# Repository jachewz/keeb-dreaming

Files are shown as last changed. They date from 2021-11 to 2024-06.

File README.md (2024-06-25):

# keeb-dreaming
Build a 68% keyboard pcb and case

Assembled keyboard (bought the caps and switches):

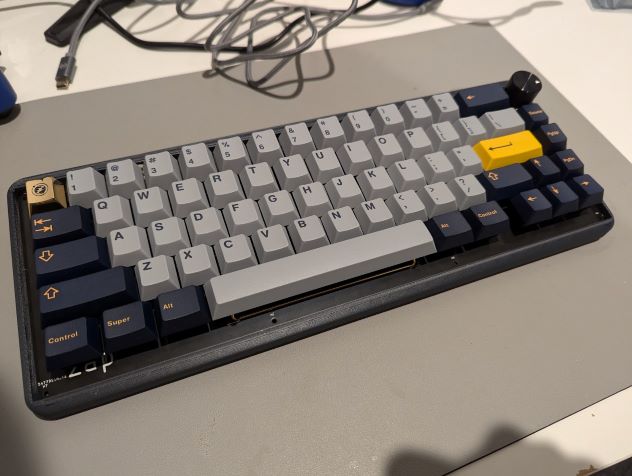
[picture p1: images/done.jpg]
Assembled keyboard with keycaps


## Features
- USB-C
- Volume knob + mute button
- Compression fit of pcb with case, no fasteners needed

## PCB

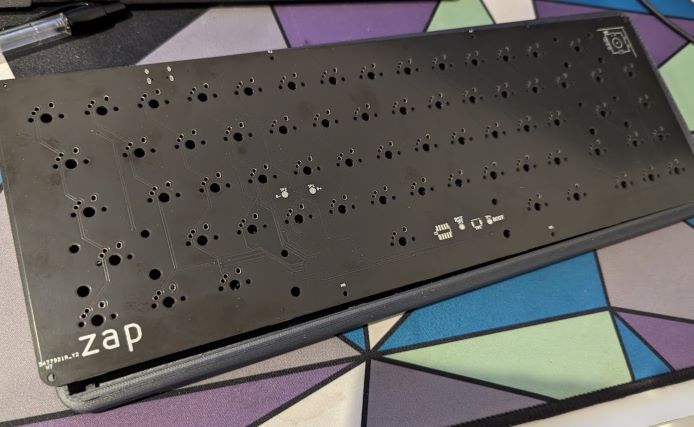
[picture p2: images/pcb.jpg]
PCB


- Learned from https://wiki.ai03.com/books/pcb-design/chapter/pcb-designer-guide
- Use KiCAD to edit the schematics and pcb design

## Firmware
- Copy [this folder](qmk/zap) into the [QMK repository's keyboards folder](https://github.com/qmk/qmk_firmware/tree/master/keyboards)
- Use the [QMK MSYS terminal tool](https://docs.qmk.fm/#/newbs_getting_started) and run `qmk compile -kb zap -km default`
- Alternatively, if you have a c compiler and make installed, run `make zap`
#### Flashing
- `make zap:default:flash`
- If that does not work try power cycling/resetting while shorting the BOOT0 pin to ground (exposed on the PCB, feel free to solder a switch on it).
- Use the [STM32 programmer](https://www.st.com/en/development-tools/stm32cubeprog.html) for further debugging and validating.

## Case

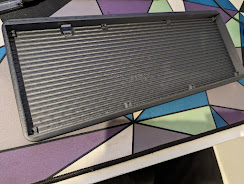
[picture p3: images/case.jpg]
Case


- In the picture above is this [case](case/3d), 3D printed, modeled using SolidWorks (free-trial)
- A layered version is also in the [case/layered](case/layered) folder

### Note
- The tolerance of the case is very small with the PCB, super tight fitting. Probably because 3D prints expand. Adjust the sizing of either the case or the PCB, and use M2 screws to fasten if needed.
- The USB-C hole needs to be higher/taller, make sure to edit it to leave at most 10mm material from the edge. The one in the picture had its hole expanded post production.
- Adding to the point above, foam can be added below but may change the placing of the USB-C hole.

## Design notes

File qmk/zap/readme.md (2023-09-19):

# zap

zap

*A short description of the keyboard/project*

* Keyboard Maintainer: [Jackson Hew](https://github.com/jacksonhew)
* Hardware Supported: *The PCBs, controllers supported*
* Hardware Availability: *Links to where you can find this hardware*

Make example for this keyboard (after setting up your build environment):

    make zap:default

Flashing example for this keyboard:

    make zap:default:flash

See the [build environment setup](https://docs.qmk.fm/#/getting_started_build_tools) and the [make instructions](https://docs.qmk.fm/#/getting_started_make_guide) for more information. Brand new to QMK? Start with our [Complete Newbs Guide](https://docs.qmk.fm/#/newbs).

## Bootloader

Enter the bootloader in 3 ways:

* **Bootmagic reset**: Hold down the key at (0,0) in the matrix (usually the top left key or Escape) and plug in the keyboard
* **Physical reset button**: Briefly press the button on the back of the PCB - some may have pads you must short instead
* **Keycode in layout**: Press the key mapped to `QK_BOOT` if it is available

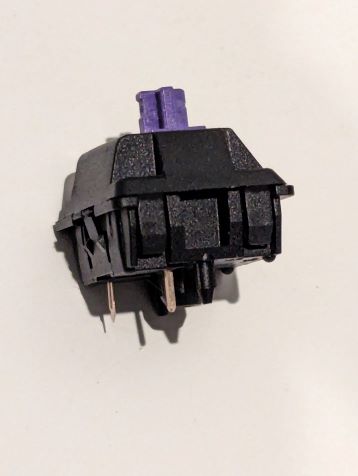
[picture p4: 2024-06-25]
images/purple_switch_shit_stems.jpg

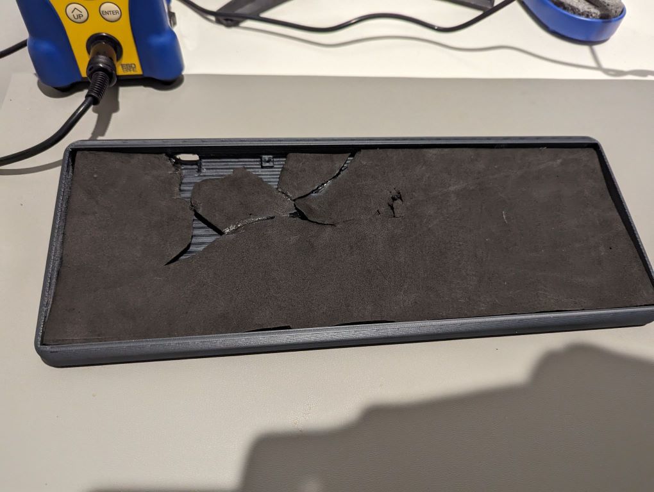
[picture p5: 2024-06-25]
images/foam.jpg

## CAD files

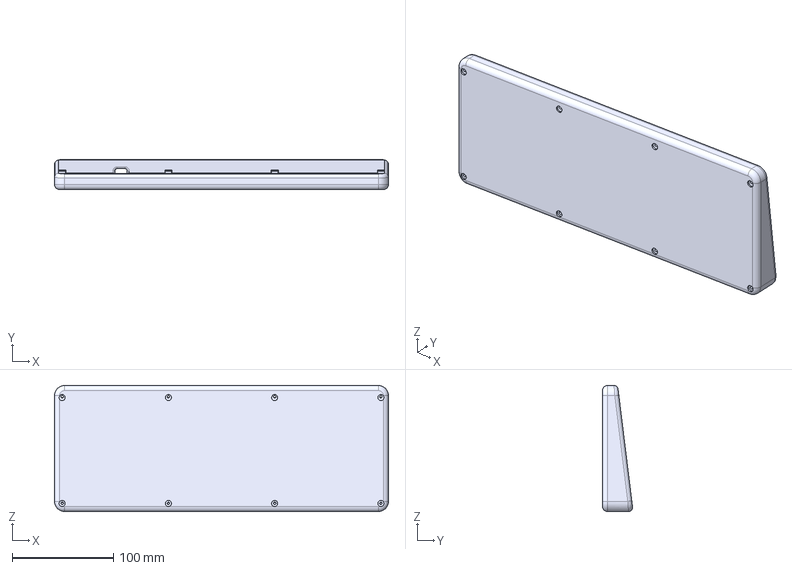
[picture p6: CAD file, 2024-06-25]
case/3d/case.step
329.4 x 29.7 x 124.3 mm

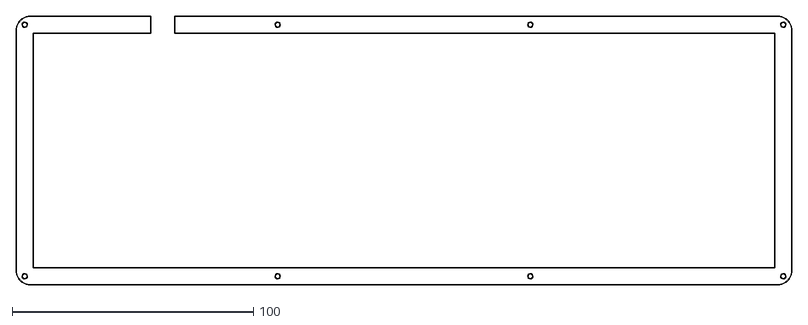
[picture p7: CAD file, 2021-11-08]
case/layered/open.dxf
321.3 x 111.3

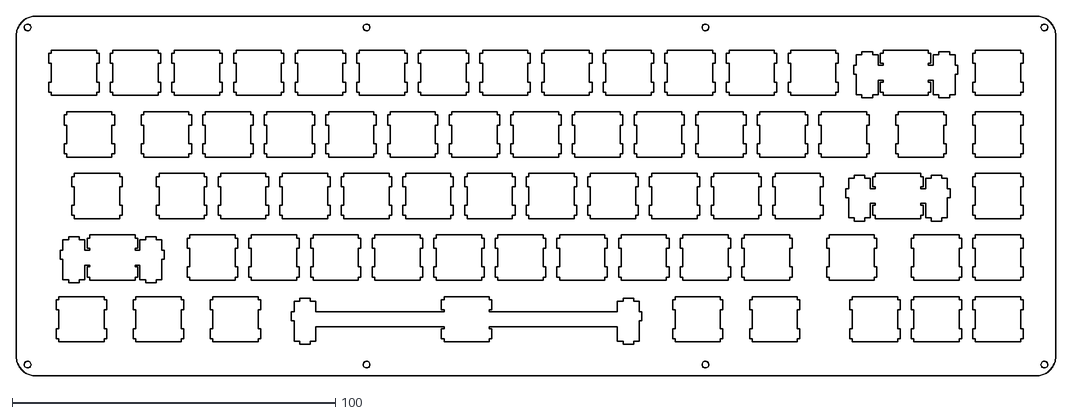
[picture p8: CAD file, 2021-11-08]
case/layered/key.dxf
321.3 x 111.3

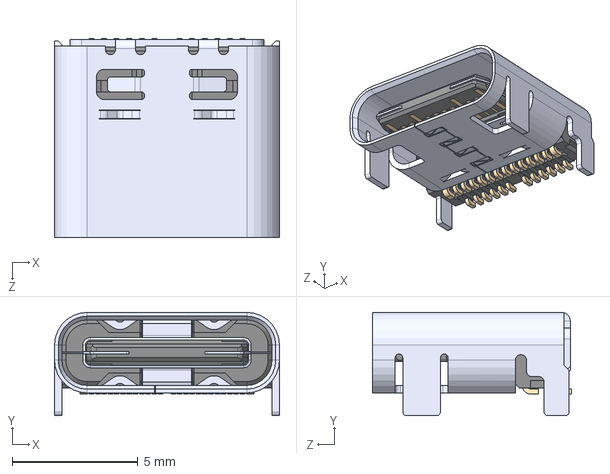
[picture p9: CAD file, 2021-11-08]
pcb/Molex Type C/105450-0101.step
8.94 x 4.10 x 7.90 mm

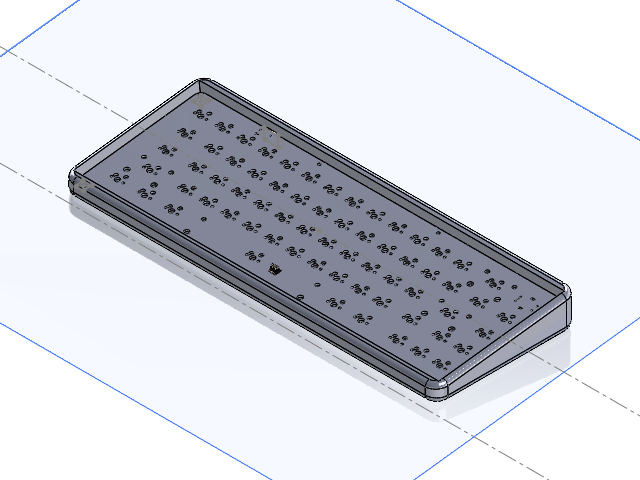
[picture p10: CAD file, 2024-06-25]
case/3d/keyboard.SLDASM
case
PinHeader_2x05_P127mm_Vertical_SMD_1.step
C_0805_2012Metric-0_1.step x 8
D_SOD_123_1.step x 67
Fuse_1206_3216Metric-1_1.step
R_0805_2012Metric-2_1.step x 5
SOT_23_6_1.step
SOT_23_1.step x 2
LQFP_48_7x7mm_P05mm_1.step
_autosave-myfirst_keeb_pcb PCB_1.step

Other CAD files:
case/3d/case.SLDPRT
case/3d/case.stl

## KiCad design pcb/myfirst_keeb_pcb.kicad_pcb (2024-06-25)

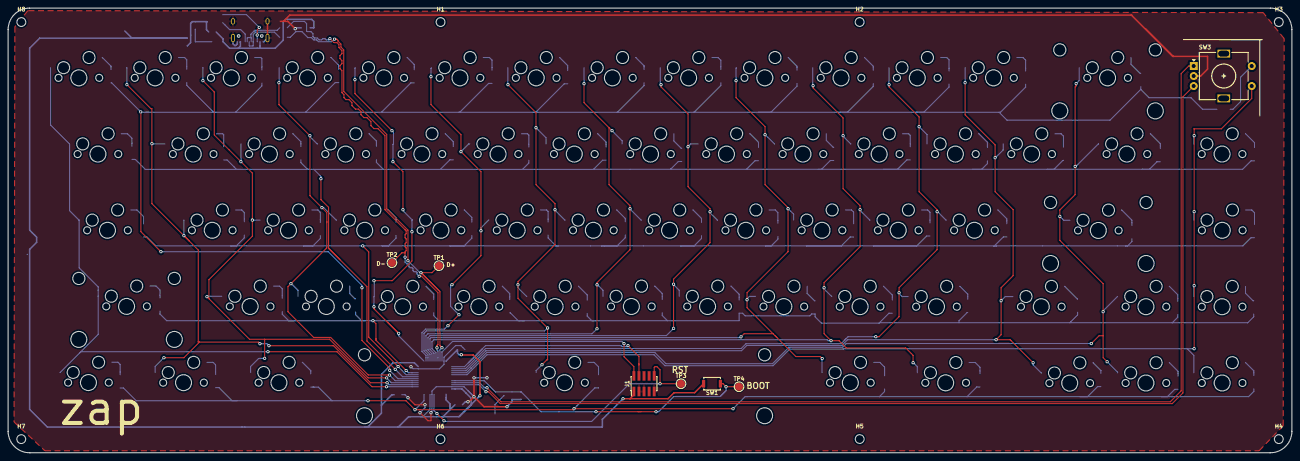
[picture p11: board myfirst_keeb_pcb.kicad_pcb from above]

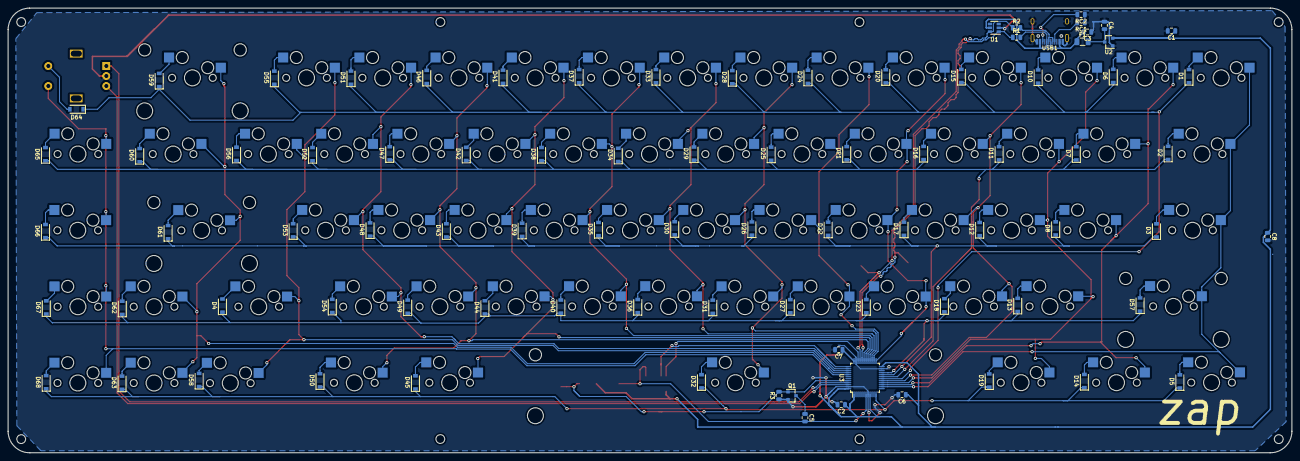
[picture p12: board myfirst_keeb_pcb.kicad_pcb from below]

Board: 2 copper layers, 320.9 x 111.1 mm, 167 parts (86 on the bottom side), 104 nets.

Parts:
C1, C2, C3, C4, C6, C7: 100nF; C_0805_2012Metric
C5: 100uF; C_0805_2012Metric
C8: 4.7uF; C_0805_2012Metric
D1, D2, D3, D4, D5, D6, D7, D8, D10, D11, D12, D13, D14, D15, D16, D17, D18, D19, D20, D21, D22, D23, D24, D25, D26, D27, D28, D29, D30, D31, D32, D33, D34, D35, D36, D37, D38, D39, D40, D41, D42, D43, D44, D45, D46, D47, D48, D49, D50, D51, D52, D53, D54, D55, D56, D57, D58, D59, D60, D61, D62, D63, D64, D65, D66, D67, D68: SOD_123; D_SOD-123
F1: 500mA; Fuse_1206_3216Metric
H1, H2, H3, H4, H5, H6, H7, H8: MountingHole; MountingHole_2.2mm_M2
J1: Conn_ARM_JTAG_SWD_10; PinHeader_2x05_P1.27mm_Vertical_SMD
MX1: ESC; MXOnly-1U-Hotswap
MX2: Tab; MXOnly-1.5U-Hotswap
MX3: CapsLk; MXOnly-1.75U-Hotswap
MX4: RShift; MXOnly-1.75U-Hotswap
MX5: Ctrl; MXOnly-1.25U-Hotswap
MX6: 1; MXOnly-1U-Hotswap
MX7: Q; MXOnly-1U-Hotswap
MX8: A; MXOnly-1U-Hotswap
MX10: 2; MXOnly-1U-Hotswap
MX11: W; MXOnly-1U-Hotswap
MX12: S; MXOnly-1U-Hotswap
MX13: Z; MXOnly-1U-Hotswap
MX14: Super; MXOnly-1.25U-Hotswap
MX15: 3; MXOnly-1U-Hotswap
MX16: E; MXOnly-1U-Hotswap
MX17: D; MXOnly-1U-Hotswap
MX18: X; MXOnly-1U-Hotswap
MX19: LAlt; MXOnly-1.25U-Hotswap
MX20: 4; MXOnly-1U-Hotswap
MX21: R; MXOnly-1U-Hotswap
MX22: F; MXOnly-1U-Hotswap
MX23: C; MXOnly-1U-Hotswap
MX24: 5; MXOnly-1U-Hotswap
MX25: T; MXOnly-1U-Hotswap
MX26: G; MXOnly-1U-Hotswap
MX27: V; MXOnly-1U-Hotswap
MX28: 6; MXOnly-1U-Hotswap
MX29: Y; MXOnly-1U-Hotswap
MX30: H; MXOnly-1U-Hotswap
MX31: B; MXOnly-1U-Hotswap
MX32: Space; MXOnly-6.25U-Hotswap
MX33: 7; MXOnly-1U-Hotswap
MX34: U; MXOnly-1U-Hotswap
MX35: J; MXOnly-1U-Hotswap
MX36: N; MXOnly-1U-Hotswap
MX37: 8; MXOnly-1U-Hotswap
MX38: I; MXOnly-1U-Hotswap
MX39: K; MXOnly-1U-Hotswap
MX40: M; MXOnly-1U-Hotswap
MX41: 9; MXOnly-1U-Hotswap
MX42: O; MXOnly-1U-Hotswap
MX43: L; MXOnly-1U-Hotswap
MX44: ,; MXOnly-1U-Hotswap
MX45: RAlt; MXOnly-1.25U-Hotswap
MX46: 0; MXOnly-1U-Hotswap
MX47: P; MXOnly-1U-Hotswap
MX48: ;; MXOnly-1U-Hotswap
MX49: .; MXOnly-1U-Hotswap
MX50: Fn; MXOnly-1.25U-Hotswap
MX51: _; MXOnly-1U-Hotswap
MX52: {; MXOnly-1U-Hotswap
MX53: "; MXOnly-1U-Hotswap
MX54: /; MXOnly-1U-Hotswap
MX55: +; MXOnly-1U-Hotswap
MX56: }; MXOnly-1U-Hotswap
MX57: LShift; MXOnly-2.25U-Hotswap
MX58: Left; MXOnly-1U-Hotswap
MX59: Backspace; MXOnly-2U-Hotswap
MX60: |; MXOnly-1.5U-Hotswap
MX61: Enter; MXOnly-2.25U-Hotswap
MX62: Up; MXOnly-1U-Hotswap
MX63: Down; MXOnly-1U-Hotswap
MX64: Del; MXOnly-1U-Hotswap
MX65: PageUp; MXOnly-1U-Hotswap
MX66: PageDown; MXOnly-1U-Hotswap
MX67: Right; MXOnly-1U-Hotswap
Q1: DTC123J; SOT-23
R1, R2: 22; R_0805_2012Metric
R3: 10k; R_0805_2012Metric
RC1, RC2: 5k1; R_0805_2012Metric
SW1: SW_Push; SW_Push_SPST_NO_Alps_SKRK
SW3: Rotary_Encoder_Switch; RotaryEncoder_Alps_EC11E-Switch_Vertical_H20mm
TP1, TP2, TP3, TP4: TestPoint; TestPoint_Pad_D2.0mm
U1: SRV05-4; SOT-23-6
U2: MCP1700-3302E_SOT23; SOT-23
U3: STM32F072CBTx; LQFP-48_7x7mm_P0.5mm
USB1: HRO-TYPE-C-31-M-12; HRO-TYPE-C-31-M-12-Assembly

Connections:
+3V3: C1.1, C2.1, C6.1, C7.1, C8.1, J1.1, SW1.2, U2.2, U3.1, U3.9, U3.24, U3.36, U3.48
BOOT0: Q1.1, R3.2, SW1.1, TP4.1, U3.44
COL0: MX1.1, MX2.1, MX3.1, MX5.1, MX57.1, U3.14
COL1: MX6.1, MX7.1, MX8.1, MX14.1, U3.15
COL2: MX10.1, MX11.1, MX12.1, MX13.1, MX19.1, U3.16
COL3: MX15.1, MX16.1, MX17.1, MX18.1, U3.17
COL4: MX20.1, MX21.1, MX22.1, MX23.1, U3.25
COL5: MX24.1, MX25.1, MX26.1, MX27.1, U3.26
COL6: MX28.1, MX29.1, MX30.1, MX31.1, MX32.1, U3.27
COL7: MX33.1, MX34.1, MX35.1, MX36.1, U3.28
COL8: MX37.1, MX38.1, MX39.1, MX40.1, U3.29
COL9: MX41.1, MX42.1, MX43.1, MX44.1, MX45.1, U3.30
COL10: MX46.1, MX47.1, MX48.1, MX49.1, MX50.1, U3.31
COL11: MX51.1, MX52.1, MX53.1, MX54.1, U3.38
COL12: MX4.1, MX55.1, MX56.1, MX58.1, U3.39
COL13: MX59.1, MX60.1, MX61.1, MX62.1, MX63.1, U3.40
COL14: MX64.1, MX65.1, MX66.1, MX67.1, SW3.S1, U3.41
D+: R1.1, TP1.1, U1.1, U3.33
D-: R2.1, TP2.1, U1.6, U3.32
ENCODER_A: SW3.A, U3.45
ENCODER_B: SW3.B, U3.46
GND: C1.2, C2.2, C3.1, C4.1, C6.2, C7.2, C8.2, J1.3, J1.5, J1.9, Q1.2, R3.1, RC1.1, RC2.1, SW3.C, U1.2, U2.1, U3.8, U3.23, U3.35, U3.47, USB1.1, USB1.12, USB1.13
NRST: C5.2, J1.10, TP3.1, U3.7
unnamed: C4.2, F1.2, U2.3
unnamed: C5.1, Q1.3
unnamed: D1.2, MX1.2
unnamed: D2.2, MX2.2
unnamed: D3.2, MX3.2
unnamed: D4.2, MX4.2
unnamed: D5.2, MX5.2
unnamed: D6.2, MX6.2
unnamed: D7.2, MX7.2
unnamed: D8.2, MX8.2
unnamed: D10.2, MX10.2
unnamed: D11.2, MX11.2
unnamed: D12.2, MX12.2
unnamed: D13.2, MX13.2
unnamed: D14.2, MX14.2
unnamed: D15.2, MX15.2
unnamed: D16.2, MX16.2
unnamed: D17.2, MX17.2
unnamed: D18.2, MX18.2
unnamed: D19.2, MX19.2
unnamed: D20.2, MX20.2
unnamed: D21.2, MX21.2
unnamed: D22.2, MX22.2
unnamed: D23.2, MX23.2
unnamed: D24.2, MX24.2
unnamed: D25.2, MX25.2
unnamed: D26.2, MX26.2
unnamed: D27.2, MX27.2
unnamed: D28.2, MX28.2
unnamed: D29.2, MX29.2
unnamed: D30.2, MX30.2
unnamed: D31.2, MX31.2
unnamed: D32.2, MX32.2
unnamed: D33.2, MX33.2
unnamed: D34.2, MX34.2
unnamed: D35.2, MX35.2
unnamed: D36.2, MX36.2
unnamed: D37.2, MX37.2
unnamed: D38.2, MX38.2
unnamed: D39.2, MX39.2
unnamed: D40.2, MX40.2
unnamed: D41.2, MX41.2
unnamed: D42.2, MX42.2
unnamed: D43.2, MX43.2
unnamed: D44.2, MX44.2
unnamed: D45.2, MX45.2
unnamed: D46.2, MX46.2
unnamed: D47.2, MX47.2
unnamed: D48.2, MX48.2
unnamed: D49.2, MX49.2
unnamed: D50.2, MX50.2
unnamed: D51.2, MX51.2
unnamed: D52.2, MX52.2
unnamed: D53.2, MX53.2
unnamed: D54.2, MX54.2
unnamed: D55.2, MX55.2
unnamed: D56.2, MX56.2
unnamed: D57.2, MX57.2
unnamed: D58.2, MX58.2
unnamed: D59.2, MX59.2
unnamed: D60.2, MX60.2
unnamed: D61.2, MX61.2
unnamed: D62.2, MX62.2
unnamed: D63.2, MX63.2
unnamed: D64.2, SW3.S2
unnamed: D65.2, MX64.2
unnamed: D66.2, MX65.2
unnamed: D67.2, MX66.2
unnamed: D68.2, MX67.2
unnamed: R1.2, USB1.6, USB1.8
unnamed: R2.2, USB1.5, USB1.7
unnamed: RC1.2, USB1.4
unnamed: RC2.2, USB1.10
ROW0: D1.1, D6.1, D10.1, D15.1, D20.1, D24.1, D28.1, D33.1, D37.1, D41.1, D46.1, D51.1, D55.1, D59.1, D64.1, U3.18
ROW1: D2.1, D7.1, D11.1, D16.1, D21.1, D25.1, D29.1, D34.1, D38.1, D42.1, D47.1, D52.1, D56.1, D60.1, D65.1, U3.19
ROW2: D3.1, D8.1, D12.1, D17.1, D22.1, D26.1, D30.1, D35.1, D39.1, D43.1, D48.1, D53.1, D61.1, D66.1, U3.20
ROW3: D4.1, D13.1, D18.1, D23.1, D27.1, D31.1, D36.1, D40.1, D44.1, D49.1, D54.1, D57.1, D62.1, D67.1, U3.21
ROW4: D5.1, D14.1, D19.1, D32.1, D45.1, D50.1, D58.1, D63.1, D68.1, U3.12
SWDCLK: J1.4, U3.37
SWDIO: J1.2, U3.34
VCC: C3.2, F1.1, U1.5, USB1.2, USB1.11

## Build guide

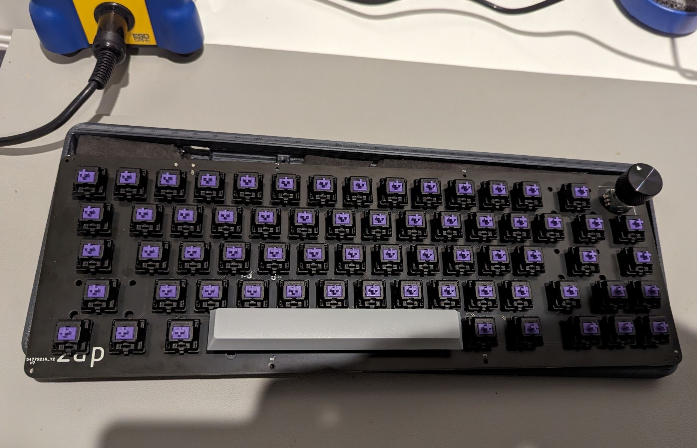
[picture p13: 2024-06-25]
images/solder_done.jpg

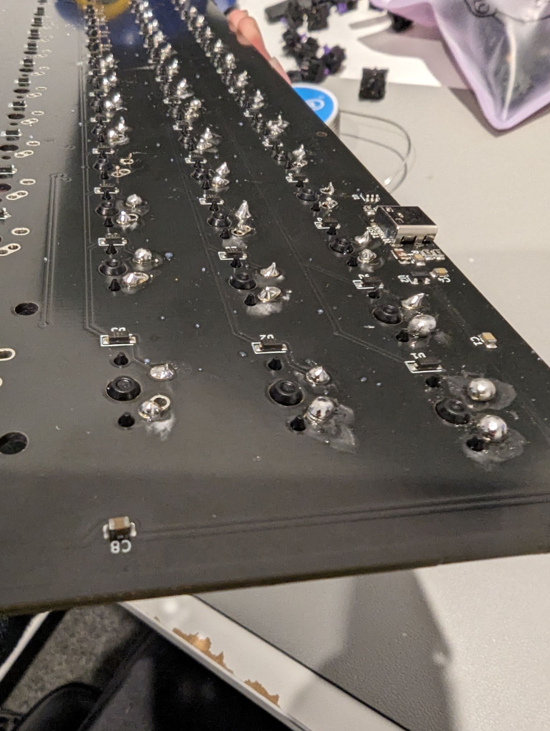
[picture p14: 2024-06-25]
images/soldering_switches_under.jpg

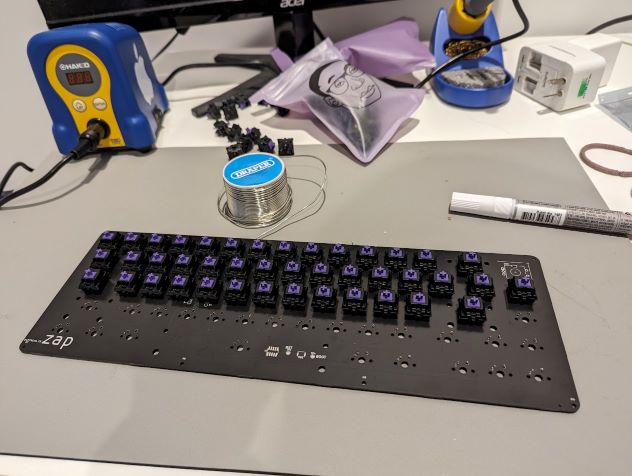
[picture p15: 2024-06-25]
images/soldering_switches.jpg

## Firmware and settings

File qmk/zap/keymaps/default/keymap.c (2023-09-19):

// Copyright 2023 QMK
// SPDX-License-Identifier: GPL-2.0-or-later

#include QMK_KEYBOARD_H

enum layers{
    _BASE,
    _FN
};

const uint16_t PROGMEM keymaps[][MATRIX_ROWS][MATRIX_COLS] = {
    /*
     *                                                                 ┌───┐
     * ┌───┬───┬───┬───┬───┬───┬───┬───┬───┬───┬───┬───┬───┬───────┐   │Enc│
     * │Esc│ 1 │ 2 │ 3 │ 4 │ 5 │ 6 │ 7 │ 8 │ 9 │ 0 │ - │ = │ Backsp│   ├───┤
     * ├───┴─┬─┴─┬─┴─┬─┴─┬─┴─┬─┴─┬─┴─┬─┴─┬─┴─┬─┴─┬─┴─┬─┴─┬─┴─┬─────┤   │Del│
     * │ Tab │ Q │ W │ E │ R │ T │ Y │ U │ I │ O │ P │ [ │ ] │  \  │   ├───┤
     * ├─────┴┬──┴┬──┴┬──┴┬──┴┬──┴┬──┴┬──┴┬──┴┬──┴┬──┴┬──┴┬──┴─────┤   │PgU│
     * │ Caps │ A │ S │ D │ F │ G │ H │ J │ K │ L │ ; │ ' │  Enter │   ├───┤
     * ├──────┴─┬─┴─┬─┴─┬─┴─┬─┴─┬─┴─┬─┴─┬─┴─┬─┴─┬─┴─┬─┴─┬─┴──────┬─┴─┐ │PgD│
     * │ Shift  │ Z │ X │ C │ V │ B │ N │ M │ , │ . │ / │ Shift  │ ↑ │ └───┘
     * ├────┬───┴┬──┴─┬─┴───┴───┴───┴───┴───┴──┬┴───┼───┼────┬───┼───┼───┐
     * │Ctrl│GUI │Alt │                        │ Alt│GUI│ Ctl│ ← │ ↓ │ → │
     * └────┴────┴────┴────────────────────────┴────┴───┴────┴───┴───┴───┘
     */
    [_BASE] = LAYOUT_68_ansi(
        KC_ESC,  KC_1,    KC_2,    KC_3,    KC_4,    KC_5,    KC_6,    KC_7,    KC_8,    KC_9,    KC_0,    KC_MINS, KC_EQL,  KC_BSPC, KC_MUTE,
        KC_TAB,  KC_Q,    KC_W,    KC_E,    KC_R,    KC_T,    KC_Y,    KC_U,    KC_I,    KC_O,    KC_P,    KC_LBRC, KC_RBRC, KC_BSLS, KC_DEL,
        KC_CAPS, KC_A,    KC_S,    KC_D,    KC_F,    KC_G,    KC_H,    KC_J,    KC_K,    KC_L,    KC_SCLN, KC_QUOT,          KC_ENT,  KC_PGUP,
        KC_LSFT,          KC_Z,    KC_X,    KC_C,    KC_V,    KC_B,    KC_N,    KC_M,    KC_COMM, KC_DOT,  KC_SLSH, KC_RSFT, KC_UP,   KC_PGDN,
        KC_LCTL, KC_LGUI, KC_LALT,                            KC_SPC,                             KC_RALT, KC_RCTL, KC_LEFT, KC_DOWN, KC_RGHT
    )
    ,
    [_FN] = LAYOUT_68_ansi(
        _______, KC_F1,   KC_F2,   KC_F3,   KC_F4,   KC_F5,   KC_F6,   KC_F7,   KC_F8,   KC_F9,   KC_F10,  KC_F11,  KC_F12,  _______, _______,
        _______, _______, _______, _______, _______, _______, _______, _______, _______, _______, _______, _______, _______, _______, _______,
        _______, _______, _______, _______, _______, _______, _______, _______, _______, _______, _______, _______,          _______, _______,
        _______,          _______, _______, _______, _______, _______, _______, _______, _______, _______, _______, _______, _______, _______,
        _______, _______, _______,                            _______,                            _______, _______, _______, _______, _______
    )
};

#if defined(ENCODER_MAP_ENABLE)
const uint16_t PROGMEM encoder_map[][NUM_ENCODERS][NUM_DIRECTIONS] = {
    [_BASE] =   { ENCODER_CCW_CW(KC_VOLD, KC_VOLU)},
    [_FN] =  { ENCODER_CCW_CW(KC_BRID, KC_BRIU)},
};
#endif

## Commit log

2021-10-10 adding drawings and rearranging folders
    [my_pcb.kicad_pcb, my_pcb.sch]
2021-10-11 symbol % footprint tables
2021-10-11 update files to 5.0+
    [my_pcb.sch, myfirst_keeb_pcb.kicad_pcb, myfirst_keeb_pcb.sch]
2021-10-12 Schematics - ATmega, USB
    [myfirst_keeb_pcb.sch]
2021-10-16 add sample of mx schematic
    [myfirst_keeb_pcb.kicad_pcb, myfirst_keeb_pcb.sch]
2021-10-26 Add matrix and change to STM32f303
    [matrix.sch, myfirst_keeb_pcb.sch]
2021-11-02 Assign 1u+ key footprints Half arranged layout
    [matrix.sch, myfirst_keeb_pcb.kicad_pcb, myfirst_keeb_pcb.sch]
2021-11-07 key layout complete. Diode todo
    [matrix.sch, myfirst_keeb_pcb.kicad_pcb]
2021-11-08 diode layout complete added case graphics on pcb
    [105450-0101.step, key.dxf, matrix.sch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]
2022-04-17 pcb wip
    [myfirst_keeb_pcb.kicad_pcb]
2022-09-25 change stm32 chip to STM32F410CBT6
    [myfirst_keeb_pcb.kicad_pcb, myfirst_keeb_pcb.sch]
2023-02-18 complete routing
    [matrix.sch, myfirst_keeb_pcb.kicad_pcb, myfirst_keeb_pcb.sch]
2023-02-20 fix track errors
    - hole too close error irrelevant because that is from the mx switch library and its meant to be
    - usb pads should be close together, its from the part's library
    [myfirst_keeb_pcb.kicad_pcb]
2023-02-21 add cringe deco text
    [myfirst_keeb_pcb.kicad_pcb]
2023-02-23 remove switch for rst, use same switch as BOOT0 - add jtag for swd
    [myfirst_keeb_pcb.kicad_pcb, myfirst_keeb_pcb.sch]
2023-03-11 moved boot button to directly under spacebar
    - easy push
    [myfirst_keeb_pcb.kicad_pcb]
2023-03-13 shorten and made data bus lengths similar
    - fix row trace unconnected
    [myfirst_keeb_pcb.kicad_pcb]
2023-04-18 add M2 mounting holes & rounded board cut-out
    [myfirst_keeb_pcb.kicad_pcb, myfirst_keeb_pcb.sch]
2023-04-22 change microcontroller cause no stock
    - shifted microcontroller position little bit nearer to usb
    - fixed filling zones
    [myfirst_keeb_pcb.kicad_pcb, myfirst_keeb_pcb.sch]
2023-04-22 move rc1 and rc2 to bottom side. adjust data line length to be similar. adjust filling zone dimensions
    [myfirst_keeb_pcb.kicad_pcb, myfirst_keeb_pcb.sch]
2023-04-22 change boot button switch footprint - smaller and more available
    [myfirst_keeb_pcb.kicad_pcb, myfirst_keeb_pcb.sch]
2023-04-22 flip boot switch and jtag conn to top
    [myfirst_keeb_pcb.kicad_pcb]
2023-10-09 switch stm32f11 to stm32f07 for usb crystal
    [matrix.sch, myfirst_keeb_pcb.kicad_pcb, myfirst_keeb_pcb.sch]
2023-10-10 change to hotswap kalih switches
    [matrix.sch, myfirst_keeb_pcb.kicad_pcb]
2024-06-25 update kicad version
    [myfirst_keeb_pcb.kicad_pcb]
2024-06-25 add case design files
    [case.SLDPRT, case.step, case.stl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]
